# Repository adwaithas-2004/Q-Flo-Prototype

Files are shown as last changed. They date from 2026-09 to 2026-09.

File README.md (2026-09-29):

# Q-Flo: fuel quality and quantity monitor (prototype v1)






An ESP32-based prototype that checks **fuel quality** by capacitive (dielectric) sensing and
measures **fuel quantity** with a flow sensor, then shows both live on a phone or laptop over
Wi-Fi. Built as a B.Tech Electronics and Communication Engineering mini project.

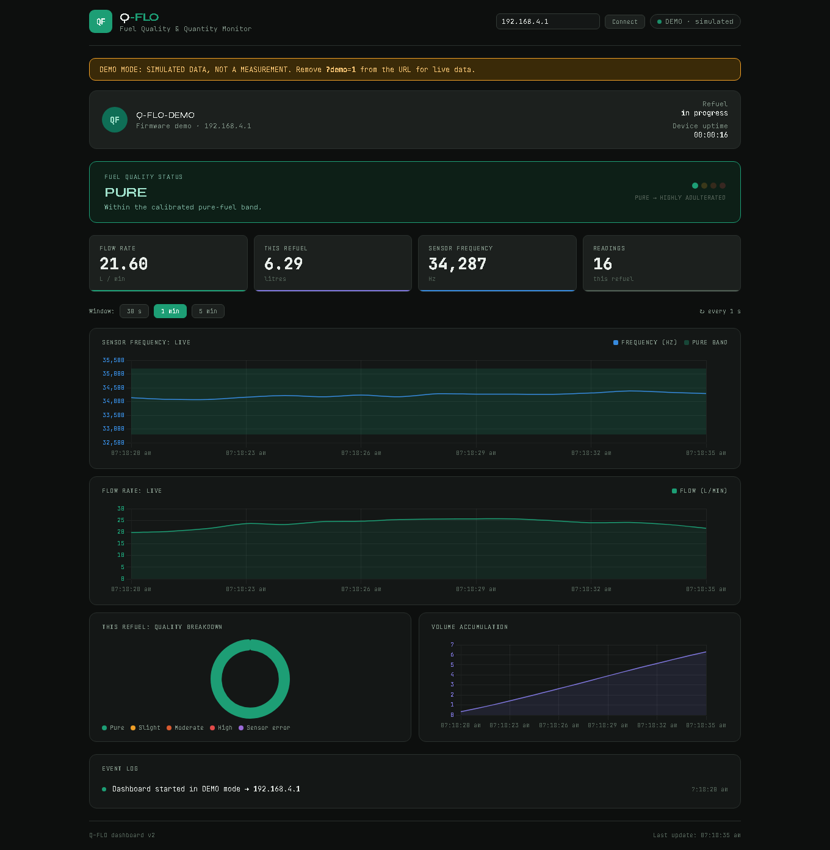
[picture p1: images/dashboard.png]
Q-Flo web dashboard (demo mode)


## Why

Adulterated fuel and short delivery at filling stations are hard for a driver to spot. Q-Flo
explores a low-cost way to watch both while fuel flows: petrol and its common adulterants have
different dielectric constants, so the capacitance of a small sensing cell changes with what's
flowing through it, while a flow meter counts the litres.

## How it works

```mermaid
flowchart LR
    cell["Capacitive cell<br/>fuel is the dielectric"] --> timer["TLC555 astable<br/>20–70 kHz"]
    timer -->|"GPIO32 · hardware pulse counter"| esp["ESP32"]
    flow["YF-S201 flow sensor<br/>hall-effect pulses"] -->|"GPIO27 · hardware pulse counter"| esp
    esp -->|"Wi-Fi access point<br/>web dashboard + JSON API"| user["Phone / laptop"]
    esp -.->|"optional BLE"| user
```

- **Quality.** The cell is the timing capacitor of a 555 oscillator: `f = 1.44 / ((R_A + 2·R_B)·C)`.
  A change in the fuel's dielectric constant shifts the frequency. The firmware compares it
  with a band recorded from pure fuel and classifies each reading as **pure**, **slightly**,
  **moderately** or **highly adulterated**, or flags a sensor fault.
- **Quantity.** The YF-S201 gives about 450 pulses per litre (7.5 Hz per L/min). The firmware
  turns pulses into flow rate and litres per refuelling session.
- **Output.** The ESP32 runs its own Wi-Fi access point and serves a live dashboard and a JSON
  API. Readings can also go out over BLE (set `QFLO_ENABLE_BLE` to 1 in `config.h`).

## Features

- Both signals counted by the ESP32's **PCNT hardware counters**, so the main loop never blocks
  and keeps up with a 70 kHz oscillator while Wi-Fi runs.
- 200 ms frequency gate with a **median filter**; flow rate from the real window length.
- **Refuelling sessions** that start and stop on flow; quality is only judged while fuel flows,
  so an empty chamber can't raise a false alarm.
- **One-touch calibration**: 10 s of readings from pure fuel set the band (mean ± 3σ, at least ±3 %).
- Settings kept in **flash (NVS)**; a **serial console** for status, calibration and CSV logging.
- A **self-contained web dashboard** served by the device (works without internet), plus a
  richer [external dashboard](dashboard/index.html) with charts and an event log.

## Hardware

| Part | Role |
|---|---|
| ESP32 DevKit (ESP32-WROOM-32) | Pulse counting, classification, Wi-Fi/BLE, web server |
| TLC555 (CMOS 555) at 3.3 V | Astable oscillator; the sensing cell is its timing capacitor |
| Capacitive sensing cell | Two plates in the fuel path |
| YF-S201 hall-effect flow sensor | Flow rate and volume |
| BAT85 + 10 kΩ | Level-shifts the 5 V flow signal to 3.3 V |

Schematic (rev B)

KiCad files are in [`hardware/kicad`](hardware/kicad). Wiring, the pin map and component
notes are in [`docs/HARDWARE.md`](docs/HARDWARE.md).

## Getting started

1. **Arduino IDE 2** → Boards Manager → install **esp32 by Espressif Systems** (3.x).
2. Open [`firmware/qflo/qflo.ino`](firmware/qflo/qflo.ino).
3. *(Optional)* copy `secrets.example.h` to `secrets.h` to set your own access-point password
   or join an existing network. `secrets.h` is git-ignored.
4. Board **ESP32 Dev Module** → Upload. Serial monitor at 115200 baud; type `help`.
5. Join the Wi-Fi network **`Q-FLO-XXXX`** (default password `qflo1234`, change it in
   `secrets.h`) and open **http://192.168.4.1**.
6. With pure fuel flowing, run a calibration from the dashboard (or type `cal` in the serial monitor).

The external dashboard: open [`dashboard/index.html`](dashboard/index.html) in a browser.
It connects to `192.168.4.1` by default; add `?device=<ip>` for another address, or `?demo=1`
to see it with simulated data.

## Repository layout

```
firmware/qflo/     ESP32 firmware (Arduino): main loop, sessions, calibration, web API
dashboard/         External web dashboard (single HTML file)
hardware/kicad/    KiCad schematic and libraries
docs/              Hardware notes, calibration procedure, device API
original/          The original mini-project sketches, as demonstrated
images/            Dashboard screenshot and schematic
```

## Limitations and lessons learned

This is a bench prototype, not a product.

- The plates add only 1–2 pF against ~20 pF of stray capacitance, so wiring and temperature
  move the reading. A larger, shielded stainless-steel cell and a capacitance-to-digital
  converter would make the fuel term dominate.
- There's no temperature compensation, and one calibrated band stands in for a proper
  multi-sample calibration.
- The YF-S201 is a water flow sensor: fine for bench demos, not rated for petrol.
- Copper electrodes react with fuel; stainless steel is the right material.

## Safety

Petrol vapour is explosive at very low concentrations. Test outdoors with small volumes, no
ignition sources and an extinguisher at hand. Never power the prototype inside a vehicle's
fuel system.

## Team

Built as a B.Tech Electronics and Communication Engineering mini project (2026) at
Mar Baselios College of Engineering and Technology (MBCET), Thiruvananthapuram, under
APJ Abdul Kalam Technological University.

- Abhishek D
- Adwaith A S ([@adwaithas-2004](https://github.com/adwaithas-2004))
- Aleena Shaji
- Dhanush S

**Project guide:** Mr. H. Aravind Sarma, Assistant Professor, Department of ECE, MBCET.

## License

© 2026 the Q-Flo team. All rights reserved; shared for viewing and evaluation. See [LICENSE](LICENSE).

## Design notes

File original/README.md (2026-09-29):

# Original mini-project sketches

These are the sketches as they were written and demonstrated for the B.Tech mini project,
kept unchanged apart from removing Wi-Fi credentials. The maintained firmware is
[`firmware/qflo`](../firmware/qflo); use that one for new builds.

| Sketch | Purpose |
|---|---|
| `Flow_sensor/` | YF-S201 flow sensor bench test (interrupt counting) |
| `Reference_freq/` | Prints the 555 frequency to record the pure-petrol reference |
| `Comparison/` | Early classifier against a single reference frequency (23,950 Hz) |
| `Final/` | Wi-Fi web-server stub that returns test data at `/data` |
| `wifi_final/` | Fuel quality + flow over Wi-Fi (`/data` JSON), the version in the project report |
| `ble_final/` | Fuel quality + flow over BLE notifications |
| `dashboard/qflo_dashboard_dark.html` | The first web dashboard (replaced by [`dashboard/index.html`](../dashboard/index.html)) |

Wi-Fi credentials were replaced with `YOUR_WIFI_SSID` / `YOUR_WIFI_PASSWORD` placeholders.

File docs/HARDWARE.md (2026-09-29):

# Hardware

## Block diagram

```
                    ┌────────────── fuel path ──────────────┐
 nozzle ──► inlet ──► YF-S201 flow sensor ──► capacitive cell ──► tank
                         │ pulses (7.5 Hz per L/min)   │ C = f(ε_fuel)
                         │                              ▼
                         │                     NE555 / TLC555 astable
                         │                              │ 20–70 kHz square wave
                         ▼                              ▼
                  GPIO27 (PCNT unit)            GPIO32 (PCNT unit)
                         └──────────► ESP32 ◄───────────┘
                                        │ Wi-Fi AP + dashboard, JSON API, (BLE)
                                        ▼
                                  phone / laptop
```

## Pin map (`firmware/qflo/config.h`)

| Signal | ESP32 pin | Notes |
|---|---|---|
| 555 output | GPIO32 | Internal pull-down enabled, so an open wire reads 0 Hz ("NO SIGNAL"). **Max 3.3 V.** |
| YF-S201 signal | GPIO27 | Internal pull-up enabled (open-collector output). **Max 3.3 V.** |
| Sensor/timer supply | 3V3 or 5V | See level-shifting below |
| GND | GND | Star-ground the 555, the cell shield and the ESP32 |

Both inputs use the ESP32's PCNT hardware counter. Any PCNT-capable GPIO works;
avoid GPIO34–39 (no internal pull resistors) and the strapping pins (0, 2, 5, 12, 15).

## Level shifting: don't skip this

The ESP32's GPIO absolute maximum is 3.6 V.

- **Timer.** Preferably use a **TLC555 or LMC555 (CMOS 555) powered from 3.3 V**. It's pin-compatible,
  runs from about 2 V, and has pA-level input currents. That matters with the MΩ timing resistors
  a pF-scale sensor needs. The bipolar NE555 is only specified from 4.5 V. If you keep an NE555 at 5 V,
  put a **10 kΩ / 20 kΩ divider** between pin 3 and GPIO32.
- **YF-S201.** It needs 5 V. If your module has a pull-up to 5 V on the signal wire (measure the idle
  voltage), add the same 10 kΩ / 20 kΩ divider. If it idles near 0 V or floats, the ESP32's internal
  pull-up to 3.3 V is enough.

## 555 timer (astable)

`f = 1.44 / ((R_A + 2·R_B) · C)` with C = sensor capacitance + stray capacitance.

Correct connections, as implemented in the **rev B schematic** ([image](../images/schematic.svg),
KiCad files in [`hardware/kicad`](../hardware/kicad)). The starred lines were wrong on the first
(rev A) board. The PCB layout isn't included because it still carries the rev A nets.

```
+3.3V ── pin 8 VCC, pin 4 RESET; C4 100 nF to GND at pin 8
U1  = TLC555CP (CMOS 555, DIP-8) at +3.3 V
R2  = R_A 10 kΩ : VCC   → pin 7 DISCH
R3  = R_B 1 MΩ  : pin 7 → pins 6 + 2            * (schematic: +5V → pin 6)
pins 2 TRIG + 6 THRES tied together             * (schematic: not connected)
J1  sensor plates: pins 2/6 → GND               (the timing capacitor)
C2  2.2 nF: remove                              * (swamps the ~1–2 pF sensor)
C3  10 nF: pin 5 CONT → GND
pin 3 OUT → GPIO32 directly (TLC555 at 3.3 V; an NE555 at 5 V would need a divider)
flow: J2 pin 3 → D1 (BAT85, cathode to sensor) → GPIO27, R4 10 kΩ pull-up to 3.3 V
```

- With R_A = 10 kΩ and R_B = 1 MΩ the duty cycle is about 50 %, and 34 kHz means about 21 pF total
  timing capacitance, most of it stray. The next cell should raise the sensor's share (see below).
- The firmware's PCNT glitch filter is 200 ns (`FREQ_GLITCH_NS`). If you change R_A/R_B so the LOW
  pulse gets very short, check the duty cycle on a scope.
- Use 1 % metal-film resistors with low temperature coefficient. Put 100 nF decoupling at pin 8
  and 10 nF at pin 5.
- Keep the sensor leads short, rigid and shielded, with the shield grounded. With only a few pF
  of sensor capacitance, moving a wire changes the reading.

## Capacitive cell

| | Prototype v1 | Lessons learned: what the next version should do |
|---|---|---|
| Electrodes | 2 copper plates, 25–35 mm, 5–7 mm gap | **SS316** concentric cylinders or interdigitated plates |
| Insulation | not specified | PTFE / PEEK spacers, fuel-resistant sealing |
| Capacitance | ~1–2 pF (smaller than stray capacitance) | ≥ 20–50 pF, so the fuel term dominates the parasitics |
| Filling | depends on flow | Flooded cell with no trapped air: vertical flow upward, fixed volume |
| Readout | 555 + pulse timing | 555 + PCNT, or better a capacitance-to-digital converter (e.g. AD7746 / FDC1004) with a guard driver |
| Temperature | none | DS18B20 or NTC inside the cell (for compensation) |
| Self-check | none | Switchable reference capacitor, so the ratio cancels 555 and resistor drift |

Copper catalyses petrol oxidation and gum formation. Avoid copper, brass and zinc in the wetted path.

## Flow sensor

The YF-S201 is a **water** flow sensor. It is rated 1–30 L/min (car nozzles often run
30–40 L/min), has hobby-grade accuracy, and its plastics are not rated for petrol. It's fine
for a bench demo with small volumes. It is not suitable for real fuel; that needs a
fuel-rated meter.

## Power

- Bench: 5 V USB is fine.
- Vehicle: 12 V battery → **automotive buck converter** (with reverse-polarity protection,
  a load-dump TVS and a fuse) → 5 V / 3.3 V. A linear AMS1117 or LM7805 dropping 12 V wastes 2 W as heat.
- The engine and usually the ignition are **off during refuelling**. The device therefore needs a
  permanent (unswitched) supply plus a low-power sleep mode, woken by a fuel-lid switch.

## Current prototype bill of materials

| Qty | Part |
|-----|---|
| 1 | ESP32 DevKit (ESP32-WROOM-32) |
| 1 | NE555 (→ replace with TLC555) + R1, R2, 10 nF, 100 nF |
| 2 | Copper plates 25–35 mm (→ SS316) |
| 1 | YF-S201 hall-effect flow sensor |
| 1 | Voltage regulator (AMS1117 / LM7805) (→ buck converter) |
| – | PCB, connectors, tubing, flow chamber |

## Safety

Petrol vapour is explosive at very low concentrations. Test outdoors or in a fume hood with
small volumes and no ignition sources, and keep an extinguisher at hand. Never power the
prototype inside a vehicle's fuel system.

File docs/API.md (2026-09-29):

# Q-FLO device API

The device always runs its own access point, **`Q-FLO-XXXX`** (password in `secrets.h`,
default `qflo1234`). The dashboard is at **http://192.168.4.1**. If it also joined a network
(`secrets.h`), it is reachable at its LAN IP and at **http://qflo.local**.

All JSON responses send `Access-Control-Allow-Origin: *`, so an external web dashboard
can call the device directly.

## Endpoints

| Method | Path | Purpose |
|---|---|---|
| GET | `/` | Built-in dashboard (single self-contained page) |
| GET | `/api/data` | Live readings, session, calibration, thresholds |
| GET | `/data` | Same as `/api/data`. The v1 path, kept so older dashboards still work |
| POST | `/api/settings` | Form fields (all optional): `pureMin`, `pureMax`, `slight`, `moderate` (Hz), `ppl` (pulses/L), `bench` (`0`/`1`), `defaults=1` |
| POST | `/api/calibrate` | Start a 10 s pure-fuel reference capture → `202` |
| POST | `/api/session/reset` | Clear the current refuelling session |

Example:

```bash
curl -X POST http://192.168.4.1/api/settings -d "pureMin=33000&pureMax=35400&bench=1"
```

## `/api/data` response

```json
{
  "freq": 34105.0,            // Hz, median-filtered            (v1 field)
  "quality": "PURE PETROL",   // label shown to the user         (v1 field)
  "flow": 12.40,              // L/min                           (v1 field)
  "total": 5.672,             // litres in the current/last refuel (v1: since boot)
  "class": "pure",            // machine key, see below
  "signal": true,             // false = no 555 signal
  "rawFreq": 34118.2,         // Hz, last 200 ms gate
  "state": "fueling",         // idle | fueling | done
  "bench": false,
  "session": {
    "litres": 5.672, "durationS": 42, "avgFreq": 34101.2, "sdFreq": 85.3, "samples": 210,
    "verdict": "PURE PETROL", "verdictClass": "pure",
    "counts": { "pure": 200, "slight": 10, "moderate": 0, "high": 0, "fault": 0, "no_signal": 0 }
  },
  "lifetime": 123.45,
  "cal": { "state": "ok", "progress": 0, "mean": 34150.0, "sd": 60.2, "samples": 50 },
  "th": { "pureMin": 33125.5, "pureMax": 35174.5, "slight": 5000, "moderate": 15000, "ppl": 450 },
  "uptimeS": 3600, "fw": "2.0.0", "ap": "Q-FLO-3A7C", "staIp": "192.168.1.42"
}
```

### Quality classes

| `class` | `quality` label | Meaning | Dashboard colour |
|---|---|---|---|
| `pure` | PURE PETROL | `pureMin ≤ f ≤ pureMax` | green |
| `slight` | SLIGHTLY ADULTERATED | `0 < f − pureMax ≤ slight` | yellow |
| `moderate` | MODERATELY ADULTERATED | `slight < f − pureMax ≤ moderate` | orange |
| `high` | HIGHLY ADULTERATED | `f − pureMax > moderate` | red |
| `fault` | SENSOR ERROR | `f < pureMin` | purple |
| `no_signal` | NO SIGNAL | `f < 1 kHz` (timer dead or disconnected) | grey |
| `waiting` | WAITING FOR FUEL | no flow, so quality is not judged | grey |

`quality` shows the **live** class while fuel flows, the **session verdict** (from the session's
mean frequency) after the refuel ends, and `WAITING FOR FUEL` before the first refuel.

## BLE (optional, `QFLO_ENABLE_BLE 1`)

- Device name: same as the access point (`Q-FLO-XXXX`)
- Service `5f1b0001-8c3e-4d6a-9a57-3b2f6e0c9a10`
- Characteristic `5f1b0002-8c3e-4d6a-9a57-3b2f6e0c9a10`: read + notify, once per second:
  `{"f":34105,"q":"pure","fl":12.40,"t":5.672,"s":"fueling"}`
- The payload is about 70 bytes, so the client must request an MTU above 23 (for example 185).
  nRF Connect and most Android/iOS libraries let you do this.
- Wi-Fi + BLE needs *Tools → Partition Scheme → Huge APP*.

## Serial console (115200 baud)

`help` · `status` · `cal` · `reset` · `bench on|off` · `csv on|off` · `ppl <n>` · `defaults`

## Security note

The API has no authentication. The access-point password is the only protection, so change it
in `secrets.h`. Before joining shared networks, add an API token and move to HTTPS/MQTT over
TLS.

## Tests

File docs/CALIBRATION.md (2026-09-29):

# Calibration and validation

Everything here works with the firmware through either the **dashboard**
(*Calibration & settings*) or the **serial console** at 115200 baud (type `help`).

> Work outdoors or in a fume hood with small volumes, no ignition sources and an
> extinguisher at hand. Keep fuel samples in labelled, closed containers.

## 1. Flow sensor (pulses per litre)

The YF-S201 datasheet figure (7.5 Hz per L/min = 450 pulses/L) is for **water**.
Petrol is less viscous, so calibrate with the fuel you'll measure.

1. Run `reset` so the session counter starts at zero.
2. Pour a known volume (at least 2 L, measured in a graduated cylinder or a 5 L
   legal-metrology measure) through the sensor at a steady, realistic rate.
3. Read **This refuel** (litres) on the dashboard.
4. New factor = `current_ppl × displayed_litres / actual_litres`. Set it with `ppl <value>`
   or in the settings form.
5. Repeat at three flow rates (slow, medium, fast), then use the average. If the factor varies
   by more than a few percent across rates, the sensor is outside its linear range at those rates.

## 2. Dielectric reference (pure band)

1. Clean and dry the cell, then flush it twice with the reference fuel.
2. Fill it completely, with no bubbles. Wait about 60 s for the reading to settle.
3. Turn on **bench mode** (`bench on`) so the device classifies without flow.
4. Start calibration (`cal`, or the dashboard button). It averages 10 s of readings and sets the pure band to
   `mean ± max(3·sd, 3 % of mean)`. Settings are stored in flash, so no re-flash is needed.
5. Do this three times with fresh fills. If the three means differ by more than the band
   width, the cell isn't repeatable yet.

Record the reference fuel for every calibration: pump or brand, date, **E-grade (E20?)**, and temperature.

## 3. Collecting a validation dataset

Turn on CSV streaming with `csv on`. The device prints five lines per second:

```
ms,raw_hz,filtered_hz,flow_lpm,session_l,class,state
123400,34118.2,34105.0,0.000,0.0000,pure,idle
```

Capture it with the Arduino IDE serial monitor (copy and paste), PuTTY logging, or a small
Python script. Save one file per run, named like `2026-10-02_run07_P+K10.csv`.

### Suggested protocol

| Factor | Levels |
|---|---|
| Base fuel | market E20 petrol from ≥ 3 pumps; diesel |
| Adulterant | kerosene, diesel (in petrol); kerosene (in diesel); water (small %) |
| Fraction (by volume) | 0, 2, 5, 10, 20, 30, 50 % |
| Replicates | ≥ 5 independent fills per level, in randomised order |
| Temperature | log it, and test at least a cool and a warm condition |

Keep a sample sheet (`data/samples.csv`) alongside the logs:

```
run_id,date,operator,base_fuel,source,adulterant,fraction_pct,temp_c,file,notes
run07,2026-10-02,AD,E20 petrol,Pump A,kerosene,10,29.5,2026-10-02_run07_P+K10.csv,
```

From this you can compute:
- A calibration curve (frequency against fraction), with its linearity and slope (sensitivity).
- A **limit of detection**: the smallest fraction distinguishable from 0 % at, say, 95 % confidence.
- Repeatability (same day) and reproducibility (different days, fills and temperatures).
- A **confusion matrix** from a blind test, where one teammate prepares the samples and another measures them.

These numbers are what a paper reviewer, a customer pilot or a grant panel will ask for.
They also form the dataset any future ML model needs.

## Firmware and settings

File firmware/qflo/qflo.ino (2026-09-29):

/*
   Q-FLO v2 - fuel quality + quantity monitor at the refuelling point

   Quality : capacitive cell (fuel = dielectric) timing an NE555 astable;
             the ESP32 counts the 555 frequency in hardware (PCNT).
   Quantity: YF-S201 turbine flow sensor, also counted in hardware.

   Board : ESP32 Dev Module, Arduino-ESP32 core 3.x
   Output: web dashboard at http://192.168.4.1 (device access point),
           JSON at /api/data (and /data for v1 dashboards), serial console.

   Wiring, calibration and API: see README.md and docs/.
*/

#include <ESPmDNS.h>
#include <WebServer.h>
#include <WiFi.h>

#include "FuelLogic.h"
#include "PulseCounter.h"
#include "Settings.h"
#include "config.h"
#include "dashboard.h"

#if __has_include("secrets.h")
#include "secrets.h"
#endif
#ifndef QFLO_AP_PASSWORD
#define QFLO_AP_PASSWORD "qflo1234"  // default; override in secrets.h
#endif

#if QFLO_ENABLE_BLE
#include <BLE2902.h>
#include <BLEDevice.h>
#include <BLEServer.h>
#endif

#define QFLO_STR_(x) #x
#define QFLO_STR(x) QFLO_STR_(x)

#if ESP_ARDUINO_VERSION_MAJOR < 3
#error "Q-FLO needs the esp32 Arduino core 3.x (Boards Manager > esp32 by Espressif Systems)"
#endif

// ---------------- HARDWARE ----------------
PulseCounter freqCounter;
PulseCounter flowCounter;
Settings settings;
WebServer server(80);
char apSsid[24];

// ---------------- LIVE READINGS ----------------
float rawHz = 0;       // last gate
float filteredHz = 0;  // median of the last FREQ_MEDIAN_WINDOW gates
float freqWindow[FREQ_MEDIAN_WINDOW];
uint8_t freqIndex = 0;
uint8_t freqFill = 0;
bool signalOk = false;
float flowLpm = 0;
FuelClass liveClass = FuelClass::NoSignal;

uint32_t lastGateUs = 0;
uint32_t lastGateMs = 0;
uint32_t lastFlowWindowMs = 0;
uint32_t lastReportMs = 0;

// ---------------- REFUELLING SESSION ----------------
// Idle -> Fueling when flow starts; Fueling -> Done after SESSION_END_IDLE_MS
// without flow. Quality is only judged while fuel is flowing, because an
// empty chamber (air) would otherwise read as "highly adulterated".
enum class SessionState : uint8_t { Idle, Fueling, Done };
SessionState sessionState = SessionState::Idle;
uint32_t sessionPulses = 0;
uint32_t sessionStartMs = 0;
uint32_t sessionEndMs = 0;
uint32_t lastFlowSeenMs = 0;
RunningStats sessionFreq;
uint32_t sessionCounts[kFuelClassCount] = {};

// ---------------- CALIBRATION ----------------
enum class CalResult : uint8_t { None, Ok, Failed };
bool calActive = false;
uint32_t calStartMs = 0;
RunningStats calStats;
CalResult calResult = CalResult::None;
float calMean = 0;
float calSd = 0;
uint32_t calSamples = 0;

// ---------------- SERIAL ----------------
bool csvMode = false;
char serialLine[48];
uint8_t serialLen = 0;

// ---------------- HELPERS ----------------
const char* sessionStateKey() {
  switch (sessionState) {
    case SessionState::Fueling: return "fueling";
    case SessionState::Done:    return "done";
    default:                    return "idle";
  }
}

const char* calResultKey() {
  if (calActive) return "running";
  switch (calResult) {
    case CalResult::Ok:     return "ok";
    case CalResult::Failed: return "failed";
    default:                return "none";
  }
}

float sessionLitres() {
  return sessionPulses / settings.pulsesPerLitre;
}

uint32_t sessionDurationMs() {
  if (sessionState == SessionState::Idle) return 0;
  uint32_t end = sessionState == SessionState::Fueling ? millis() : sessionEndMs;
  return end - sessionStartMs;
}

bool fuelPresent() {
  return settings.benchMode ||
         (sessionState == SessionState::Fueling && flowLpm >= FLOW_START_LPM);
}

FuelClass sessionVerdict() {
  if (sessionFreq.n == 0) {
    return sessionCounts[(uint8_t)FuelClass::NoSignal] ? FuelClass::NoSignal : FuelClass::Waiting;
  }
  return classifyFrequency(sessionFreq.mean, settings.th, FREQ_MIN_VALID_HZ);
}

// What the user should see right now: the live reading while fuel flows,
// the result of the last refuel afterwards.
FuelClass displayedClass() {
  if (settings.benchMode || sessionState == SessionState::Fueling) return liveClass;
  if (sessionState == SessionState::Done) return sessionVerdict();
  return liveClass;  // Idle: Waiting or NoSignal
}

// ---------------- SESSION ----------------
void startSession(uint32_t nowMs) {
  sessionState = SessionState::Fueling;
  sessionPulses = 0;
  sessionStartMs = nowMs;
  sessionFreq.reset();
  memset(sessionCounts, 0, sizeof(sessionCounts));
  Serial.println(F(">> Refuelling started"));
}

void endSession() {
  sessionState = SessionState::Done;
  sessionEndMs = lastFlowSeenMs;
  settings.saveLifetime();
  Serial.printf(">> Refuelling finished: %.3f L in %lu s, avg %.0f Hz -> %s\n",
                sessionLitres(), (unsigned long)(sessionDurationMs() / 1000),
                sessionFreq.mean, fuelClassLabel(sessionVerdict()));
}

void resetSession() {
  sessionState = SessionState::Idle;
  sessionPulses = 0;
  sessionFreq.reset();
  memset(sessionCounts, 0, sizeof(sessionCounts));
}

// ---------------- CALIBRATION ----------------
// Fill the cell with known-pure fuel, then start: the pure band becomes
// mean +/- max(k*sd, pct*mean) of the readings over CAL_DURATION_MS.
void startCalibration() {
  calActive = true;
  calStartMs = millis();
  calStats.reset();
  Serial.println(F(">> Calibration started: keep known-pure fuel in the sensor"));
}

void updateCalibration() {
  if (!calActive || millis() - calStartMs < CAL_DURATION_MS) return;
  calActive = false;
  calSamples = calStats.n;
  if (calStats.n < CAL_MIN_SAMPLES) {
    calResult = CalResult::Failed;
    Serial.println(F(">> Calibration failed: no stable 555 signal"));
    return;
  }
  calMean = calStats.mean;
  calSd = calStats.sd();
  float halfBand = max(CAL_SIGMA_K * calSd, CAL_MIN_HALF_BAND_PCT * calMean);
  settings.th.pureMinHz = calMean - halfBand;
  settings.th.pureMaxHz = calMean + halfBand;
  settings.save();
  calResult = CalResult::Ok;
  Serial.printf(">> Calibration OK: mean %.1f Hz, sd %.1f Hz (n=%lu) -> pure band %.0f..%.0f Hz\n",
                calMean, calSd, (unsigned long)calSamples,
                settings.th.pureMinHz, settings.th.pureMaxHz);
}

// ---------------- MEASUREMENT ----------------
void updateFrequency() {
  uint32_t nowUs = micros();
  uint32_t edges = freqCounter.take();
  uint32_t elapsedUs = nowUs - lastGateUs;
  lastGateUs = nowUs;
  if (elapsedUs == 0) return;

  rawHz = edges * 1e6f / elapsedUs;
  freqWindow[freqIndex] = rawHz;
  freqIndex = (freqIndex + 1) % FREQ_MEDIAN_WINDOW;
  if (freqFill < FREQ_MEDIAN_WINDOW) freqFill++;
  filteredHz = medianOf(freqWindow, freqFill);
  signalOk = filteredHz >= FREQ_MIN_VALID_HZ;

  FuelClass c = classifyFrequency(filteredHz, settings.th, FREQ_MIN_VALID_HZ);
  liveClass = (c == FuelClass::NoSignal || fuelPresent()) ? c : FuelClass::Waiting;

  if (calActive && rawHz >= FREQ_MIN_VALID_HZ) calStats.add(rawHz);

  if (sessionState == SessionState::Fueling && fuelPresent()) {
    sessionCounts[(uint8_t)c]++;
    if (signalOk) sessionFreq.add(filteredHz);
  }

  if (csvMode) {
    Serial.printf("%lu,%.1f,%.1f,%.3f,%.4f,%s,%s\n", (unsigned long)millis(), rawHz, filteredHz,
                  flowLpm, sessionLitres(), fuelClassKey(liveClass), sessionStateKey());
  }
}

void updateFlow() {
  uint32_t nowMs = millis();
  uint32_t pulses = flowCounter.take();
  uint32_t elapsedMs = nowMs - lastFlowWindowMs;
  lastFlowWindowMs = nowMs;

  // Use the real window length: the v1 code assumed exactly 1 s, but its
  // loop took ~1.2 s (and up to 40 s with no 555 signal).
  float litres = pulses / settings.pulsesPerLitre;
  flowLpm = elapsedMs ? litres * 60000.0f / elapsedMs : 0;
  settings.lifetimeLitres += litres;

  if (flowLpm >= FLOW_START_LPM) {
    if (sessionState != SessionState::Fueling) startSession(nowMs);
    lastFlowSeenMs = nowMs;
  }
  if (sessionState == SessionState::Fueling) {
    sessionPulses += pulses;
    if (nowMs - lastFlowSeenMs >= SESSION_END_IDLE_MS) endSession();
  }
}

// ---------------- JSON ----------------
size_t buildDataJson(char* out, size_t cap) {
  FuelClass shown = displayedClass();
  FuelClass verdict = sessionVerdict();
  uint32_t calProgress = calActive ? min<uint32_t>(100, (millis() - calStartMs) * 100 / CAL_DURATION_MS) : 0;
  const uint32_t* k = sessionCounts;

  int n = snprintf(out, cap,
    "{\"freq\":%.1f,\"quality\":\"%s\",\"flow\":%.2f,\"total\":%.3f,"
    "\"class\":\"%s\",\"signal\":%s,\"rawFreq\":%.1f,\"state\":\"%s\",\"bench\":%s,"
    "\"session\":{\"litres\":%.3f,\"durationS\":%lu,\"avgFreq\":%.1f,\"sdFreq\":%.1f,\"samples\":%lu,"
    "\"verdict\":\"%s\",\"verdictClass\":\"%s\","
    "\"counts\":{\"pure\":%lu,\"slight\":%lu,\"moderate\":%lu,\"high\":%lu,\"fault\":%lu,\"no_signal\":%lu}},"
    "\"lifetime\":%.2f,"
    "\"cal\":{\"state\":\"%s\",\"progress\":%lu,\"mean\":%.1f,\"sd\":%.1f,\"samples\":%lu},"
    "\"th\":{\"pureMin\":%.1f,\"pureMax\":%.1f,\"slight\":%.1f,\"moderate\":%.1f,\"ppl\":%.2f},"
    "\"uptimeS\":%lu,\"fw\":\"%s\",\"ap\":\"%s\",\"staIp\":\"%s\"}",
    filteredHz, fuelClassLabel(shown), flowLpm, sessionLitres(),
    fuelClassKey(shown), signalOk ? "true" : "false", rawHz, sessionStateKey(),
    settings.benchMode ? "true" : "false",
    sessionLitres(), (unsigned long)(sessionDurationMs() / 1000), sessionFreq.mean,
    sessionFreq.sd(), (unsigned long)sessionFreq.n,
    fuelClassLabel(verdict), fuelClassKey(verdict),
    (unsigned long)k[(uint8_t)FuelClass::Pure], (unsigned long)k[(uint8_t)FuelClass::Slight],
    (unsigned long)k[(uint8_t)FuelClass::Moderate], (unsigned long)k[(uint8_t)FuelClass::High],
    (unsigned long)k[(uint8_t)FuelClass::SensorFault], (unsigned long)k[(uint8_t)FuelClass::NoSignal],
    settings.lifetimeLitres,
    calResultKey(), (unsigned long)calProgress, calMean, calSd, (unsigned long)calSamples,
    settings.th.pureMinHz, settings.th.pureMaxHz, settings.th.slightBandHz,
    settings.th.moderateBandHz, settings.pulsesPerLitre,
    (unsigned long)(millis() / 1000), QFLO_FW_VERSION, apSsid,
    WiFi.status() == WL_CONNECTED ? WiFi.localIP().toString().c_str() : "");
  return n > 0 ? min<size_t>(n, cap - 1) : 0;
}

// ---------------- WEB ----------------
void sendCors() {
  server.sendHeader("Access-Control-Allow-Origin", "*");
  server.sendHeader("Access-Control-Allow-Methods", "GET, POST, OPTIONS");
  server.sendHeader("Access-Control-Allow-Headers", "Content-Type");
}

void sendJson(int code, const char* body) {
  sendCors();
  server.sendHeader("Cache-Control", "no-store");
  server.send(code, "application/json", body);
}

void handleData() {
  static char json[1400];
  buildDataJson(json, sizeof(json));
  sendJson(200, json);
}

// POST /api/settings  (form fields, all optional)
// pureMin, pureMax, slight, moderate [Hz], ppl [pulses/L], bench [0|1], defaults [1]
void handleSettings() {
  if (server.hasArg("defaults")) {
    settings.setDefaults();
    settings.save();
    sendJson(200, "{\"ok\":true}");
    return;
  }
  Thresholds th = settings.th;
  if (server.hasArg("pureMin"))  th.pureMinHz = server.arg("pureMin").toFloat();
  if (server.hasArg("pureMax"))  th.pureMaxHz = server.arg("pureMax").toFloat();
  if (server.hasArg("slight"))   th.slightBandHz = server.arg("slight").toFloat();
  if (server.hasArg("moderate")) th.moderateBandHz = server.arg("moderate").toFloat();
  if (!thresholdsValid(th)) {
    sendJson(400, "{\"ok\":false,\"error\":\"need 0 < pureMin < pureMax and 0 < slight < moderate\"}");
    return;
  }
  float ppl = server.hasArg("ppl") ? server.arg("ppl").toFloat() : settings.pulsesPerLitre;
  if (!(ppl > 1 && ppl < 100000)) {
    sendJson(400, "{\"ok\":false,\"error\":\"ppl out of range\"}");
    return;
  }
  settings.th = th;
  settings.pulsesPerLitre = ppl;
  if (server.hasArg("bench")) settings.benchMode = server.arg("bench") == "1";
  settings.save();
  sendJson(200, "{\"ok\":true}");
}

void handleCalibrate() {
  startCalibration();
  sendJson(202, "{\"ok\":true,\"durationMs\":" QFLO_STR(CAL_DURATION_MS) "}");
}

void handleSessionReset() {
  resetSession();
  sendJson(200, "{\"ok\":true}");
}

void setupWeb() {
  server.on("/", HTTP_GET, [] { server.send_P(200, "text/html; charset=utf-8", DASHBOARD_HTML); });
  server.on("/data", HTTP_GET, handleData);      // v1 path, kept for existing dashboards
  server.on("/api/data", HTTP_GET, handleData);
  server.on("/api/settings", HTTP_POST, handleSettings);
  server.on("/api/calibrate", HTTP_POST, handleCalibrate);
  server.on("/api/session/reset", HTTP_POST, handleSessionReset);
  server.onNotFound([] {
    if (server.method() == HTTP_OPTIONS) {  // CORS preflight for external dashboards
      sendCors();
      server.send(204);
    } else {
      sendJson(404, "{\"error\":\"not found\"}");
    }
  });
  server.begin();
}

// ---------------- WI-FI ----------------
void setupWifi() {
  uint64_t mac = ESP.getEfuseMac();
  snprintf(apSsid, sizeof(apSsid), "%s%02X%02X", AP_SSID_PREFIX,
           (uint8_t)(mac >> 32), (uint8_t)(mac >> 40));

  WiFi.setHostname(HOSTNAME);
#ifdef QFLO_STA_SSID
  WiFi.mode(WIFI_AP_STA);
  WiFi.setAutoReconnect(true);
  WiFi.begin(QFLO_STA_SSID, QFLO_STA_PASSWORD);  // non-blocking; v1 waited forever here
#else
  WiFi.mode(WIFI_AP);
#endif
  WiFi.softAP(apSsid, QFLO_AP_PASSWORD);

  if (MDNS.begin(HOSTNAME)) MDNS.addService("http", "tcp", 80);

  Serial.printf("Access point: %s  ->  http://%s\n", apSsid, WiFi.softAPIP().toString().c_str());
}

void announceStationIp() {
#ifdef QFLO_STA_SSID
  static bool announced = false;
  bool connected = WiFi.status() == WL_CONNECTED;
  if (connected && !announced) {
    Serial.printf("Joined %s  ->  http://%s  (or http://%s.local)\n", QFLO_STA_SSID,
                  WiFi.localIP().toString().c_str(), HOSTNAME);
  }
  announced = connected;
#endif
}

// ---------------- BLE (optional) ----------------
#if QFLO_ENABLE_BLE
BLECharacteristic* bleData = nullptr;

void setupBle() {
  BLEDevice::init(apSsid);
  BLEServer* bleServer = BLEDevice::createServer();
  bleServer->advertiseOnDisconnect(true);  // v1 became invisible after the first disconnect
  BLEService* service = bleServer->createService(BLE_SERVICE_UUID);
  bleData = service->createCharacteristic(
      BLE_DATA_UUID, BLECharacteristic::PROPERTY_READ | BLECharacteristic::PROPERTY_NOTIFY);
  bleData->addDescriptor(new BLE2902());
  service->start();
  BLEAdvertising* advertising = BLEDevice::getAdvertising();
  advertising->addServiceUUID(BLE_SERVICE_UUID);
  advertising->start();
}

// Compact JSON (~70 bytes): clients must request an MTU > 23 to receive it whole.
void bleNotify() {
  char buf[128];
  int n = snprintf(buf, sizeof(buf), "{\"f\":%.0f,\"q\":\"%s\",\"fl\":%.2f,\"t\":%.3f,\"s\":\"%s\"}",
                   filteredHz, fuelClassKey(displayedClass()), flowLpm, sessionLitres(),
                   sessionStateKey());
  if (n <= 0) return;
  bleData->setValue((uint8_t*)buf, min<size_t>(n, sizeof(buf) - 1));
  bleData->notify();
}
#endif

// ---------------- SERIAL ----------------
void printReport() {
  Serial.println(F("------ Q-FLO ------"));
  if (signalOk) {
    Serial.printf("Frequency : %.0f Hz (last gate %.0f Hz)\n", filteredHz, rawHz);
  } else {
    Serial.println(F("Frequency : NO SIGNAL - check 555 / sensor wiring"));
  }
  Serial.printf("Quality   : %s%s\n", fuelClassLabel(displayedClass()),
                settings.benchMode ? "  [bench mode]" : "");
  Serial.printf("Flow rate : %.2f L/min\n", flowLpm);
  Serial.printf("This fill : %.3f L (%s, %lu s)\n", sessionLitres(), sessionStateKey(),
                (unsigned long)(sessionDurationMs() / 1000));
  Serial.printf("Lifetime  : %.2f L\n", settings.lifetimeLitres);
}

void printHelp() {
  Serial.println(F(
    "Commands:\n"
    "  help          this list\n"
    "  status        print a report now\n"
    "  cal           capture the pure-fuel reference (10 s)\n"
    "  reset         clear the current refuelling session\n"
    "  bench on|off  classify without flow (static samples)\n"
    "  csv on|off    stream raw data as CSV, 5 lines/s\n"
    "  ppl <n>       set flow pulses per litre\n"
    "  defaults      restore factory thresholds"));
}

void runCommand(char* line) {
  char* cmd = strtok(line, " ");
  char* arg = strtok(nullptr, " ");
  if (!cmd) return;
  String c(cmd);
  c.toLowerCase();
  bool on = arg && (strcmp(arg, "on") == 0 || strcmp(arg, "1") == 0);

  if (c == "help") printHelp();
  else if (c == "status") printReport();
  else if (c == "cal") startCalibration();
  else if (c == "reset") { resetSession(); Serial.println(F(">> Session cleared")); }
  else if (c == "bench") { settings.benchMode = on; settings.save(); Serial.printf(">> Bench mode %s\n", on ? "ON" : "OFF"); }
  else if (c == "csv") {
    csvMode = on;
    if (on) Serial.println(F("ms,raw_hz,filtered_hz,flow_lpm,session_l,class,state"));
  }
  else if (c == "ppl" && arg) {
    float ppl = atof(arg);
    if (ppl > 1 && ppl < 100000) { settings.pulsesPerLitre = ppl; settings.save(); Serial.printf(">> %.2f pulses/L saved\n", ppl); }
    else Serial.println(F(">> ppl out of range"));
  }
  else if (c == "defaults") { settings.setDefaults(); settings.save(); Serial.println(F(">> Defaults restored")); }
  else Serial.println(F("Unknown command - type 'help'"));
}

void handleSerial() {
  while (Serial.available()) {
    char ch = Serial.read();
    if (ch == '\r') continue;
    if (ch == '\n') {
      serialLine[serialLen] = '\0';
      runCommand(serialLine);
      serialLen = 0;
    } else if (serialLen < sizeof(serialLine) - 1) {
      serialLine[serialLen++] = ch;
    }
  }
}

// ---------------- SETUP ----------------
void setup() {
  Serial.begin(115200);
  delay(200);
  Serial.printf("\nQ-FLO firmware %s\n", QFLO_FW_VERSION);

  settings.load();

  // Pull-down on the 555 input: a disconnected sensor reads 0 Hz instead of noise.
  if (!freqCounter.begin(PIN_FREQ, FREQ_GLITCH_NS, GPIO_PULLDOWN_ONLY)) {
    Serial.println(F("ERROR: frequency counter init failed"));
  }
  // YF-S201 output is open-collector: needs a pull-up.
  if (!flowCounter.begin(PIN_FLOW, FLOW_GLITCH_NS, GPIO_PULLUP_ONLY)) {
    Serial.println(F("ERROR: flow counter init failed"));
  }
  lastGateUs = micros();
  lastGateMs = lastFlowWindowMs = millis();

  setupWifi();
  setupWeb();
#if QFLO_ENABLE_BLE
  setupBle();
#endif
  printHelp();
}

// ---------------- LOOP ----------------
// Nothing in here blocks, so the web server answers immediately
// (v1 blocked ~1.2 s per loop, and ~40 s when the 555 had no signal).
void loop() {
  server.handleClient();
  handleSerial();

  uint32_t now = millis();
  if (now - lastGateMs >= FREQ_GATE_MS) {
    lastGateMs = now;
    updateFrequency();
  }
  if (now - lastFlowWindowMs >= FLOW_WINDOW_MS) {
    updateFlow();
  }
  updateCalibration();

  if (now - lastReportMs >= REPORT_INTERVAL_MS) {
    lastReportMs = now;
    if (!csvMode) printReport();
    announceStationIp();
#if QFLO_ENABLE_BLE
    bleNotify();
#endif
  }
  delay(2);
}

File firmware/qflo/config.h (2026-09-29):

#pragma once

// Q-FLO build-time configuration.
// Values marked "default" are only used until you change them from the
// dashboard / serial console; after that the saved values (NVS) win.

#define QFLO_FW_VERSION "2.0.0"

// ---------------- PINS (ESP32 DevKit) ----------------
// Both inputs are 3.3 V only. If the NE555 or the YF-S201 runs from 5 V,
// put a divider / level shifter in front of the pin (see docs/HARDWARE.md).
#define PIN_FREQ 32   // NE555 output (capacitive fuel sensor)
#define PIN_FLOW 27   // YF-S201 flow sensor signal

// ---------------- FREQUENCY MEASUREMENT ----------------
// The 555 output is counted in hardware (PCNT) over a fixed gate.
// 200 ms gate -> 1 count = 5 Hz resolution (pulseIn() gave ~1.2 kHz per sample).
#define FREQ_GATE_MS        200
#define FREQ_MEDIAN_WINDOW  5        // median of the last 5 gates (~1 s)
#define FREQ_MIN_VALID_HZ   1000.0f  // below this the oscillator is treated as dead
#define FREQ_GLITCH_NS      200      // keep short: a 555 with R1 >> R2 has very short LOW pulses

// ---------------- FLOW MEASUREMENT ----------------
// YF-S201 datasheet: f(Hz) = 7.5 x Q(L/min)  ->  7.5 x 60 = 450 pulses per litre.
// That figure is for water; calibrate with petrol (docs/CALIBRATION.md).
#define FLOW_PULSES_PER_LITRE_DEFAULT 450.0f
#define FLOW_WINDOW_MS       1000
#define FLOW_GLITCH_NS       10000
#define FLOW_START_LPM       0.5f    // flow above this starts / sustains a refuelling session
#define SESSION_END_IDLE_MS  10000   // a session ends after this long without flow

// ---------------- CLASSIFICATION DEFAULTS ----------------
// Reproduces Table 2 of the Q-FLO paper. Re-run the calibration ("cal") with
// known-pure fuel on your own sensor cell before trusting these numbers.
#define PURE_MIN_HZ_DEFAULT      23950.0f
#define PURE_MAX_HZ_DEFAULT      34196.0f
#define SLIGHT_BAND_HZ_DEFAULT    5000.0f   // pureMax < f <= pureMax + 5 kHz   (~ up to 10 %)
#define MODERATE_BAND_HZ_DEFAULT 15000.0f   // pureMax + 5 kHz < f <= + 15 kHz  (~ 10-30 %)

// ---------------- CALIBRATION ----------------
// Pure band = mean +/- max(CAL_SIGMA_K * sd, CAL_MIN_HALF_BAND_PCT * mean)
#define CAL_DURATION_MS        10000
#define CAL_MIN_SAMPLES        20
#define CAL_SIGMA_K            3.0f
#define CAL_MIN_HALF_BAND_PCT  0.03f

// ---------------- NETWORK ----------------
// The device always starts its own access point (Q-FLO-XXXX, dashboard at
// http://192.168.4.1). Put credentials in secrets.h to also join a network.
#define AP_SSID_PREFIX "Q-FLO-"
#define HOSTNAME       "qflo"        // http://qflo.local on a shared network

// ---------------- REPORTING ----------------
#define REPORT_INTERVAL_MS 1000

// ---------------- OPTIONAL BLE ----------------
// Wi-Fi + Bluetooth together do not fit the default partition table:
// set Tools > Partition Scheme > "Huge APP (3MB No OTA/1MB SPIFFS)" when enabling.
#ifndef QFLO_ENABLE_BLE
#define QFLO_ENABLE_BLE 0
#endif
#define BLE_SERVICE_UUID "5f1b0001-8c3e-4d6a-9a57-3b2f6e0c9a10"
#define BLE_DATA_UUID    "5f1b0002-8c3e-4d6a-9a57-3b2f6e0c9a10"

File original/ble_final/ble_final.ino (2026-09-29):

#include <BLEDevice.h>
#include <BLEServer.h>
#include <BLEUtils.h>
#include <BLE2902.h>

// ---------------- PINS ----------------
#define FREQ_PIN 32
#define FLOW_PIN 27

// ---------------- PETROL RANGE ----------------
float F_petrol_min = 23950.0;
float F_petrol_max = 34196.0;

// ---------------- FLOW VARIABLES ----------------
volatile int pulseCount = 0;
float flowRate = 0;
float totalLitres = 0;

// ---------------- BLE ----------------
BLECharacteristic *pCharacteristic;

// ---------------- FLOW INTERRUPT ----------------
void IRAM_ATTR pulseCounter() {
  pulseCount++;
}

// ---------------- FREQUENCY ----------------
float measureFrequency() {
  unsigned long tH = pulseIn(FREQ_PIN, HIGH);
  unsigned long tL = pulseIn(FREQ_PIN, LOW);

  if (tH == 0 || tL == 0) return 0;

  return 1000000.0 / (tH + tL);
}

float getStableFreq() {
  float sum = 0;
  for(int i=0;i<20;i++) {
    sum += measureFrequency();
    delay(10);
  }
  return sum / 20;
}

// ---------------- FLOW CALCULATION ----------------
void calculateFlow() {
  static unsigned long lastTime = 0;

  if (millis() - lastTime >= 1000) {

    detachInterrupt(digitalPinToInterrupt(FLOW_PIN));

    flowRate = (pulseCount / 7.5);   // L/min
    float flowLitres = flowRate / 60.0;

    totalLitres += flowLitres;

    pulseCount = 0;

    attachInterrupt(digitalPinToInterrupt(FLOW_PIN), pulseCounter, RISING);

    lastTime = millis();
  }
}

// ---------------- CLASSIFICATION ----------------
String classifyFuel(float f) {

  if (f >= F_petrol_min && f <= F_petrol_max) {
    return "PURE PETROL";
  }


  float deviation = f - F_petrol_max;

  if (deviation < 15000) {
    return "SLIGHTLY ADULTERATED";
  }
  else if (deviation < 25000) {
    return "MODERATELY ADULTERATED";
  }
  else {
    return "HIGHLY ADULTERATED";
  }
}

// ---------------- BLE SETUP ----------------
void setupBLE() {
  BLEDevice::init("Q-FLO");

  BLEServer *server = BLEDevice::createServer();
  BLEService *service = server->createService("1234");

  pCharacteristic = service->createCharacteristic(
    "5678",
    BLECharacteristic::PROPERTY_NOTIFY | BLECharacteristic::PROPERTY_READ
  );

  pCharacteristic->addDescriptor(new BLE2902());

  service->start();
  BLEDevice::getAdvertising()->start();
}

// ---------------- SETUP ----------------
void setup() {
  Serial.begin(115200);

  pinMode(FREQ_PIN, INPUT);
  pinMode(FLOW_PIN, INPUT);

  attachInterrupt(digitalPinToInterrupt(FLOW_PIN), pulseCounter, RISING);

  setupBLE();
}

// ---------------- LOOP ----------------
void loop() {

  // 🔷 Frequency
  float F_now = getStableFreq();
  String fuelStatus = classifyFuel(F_now);

  // 🔷 Flow
  calculateFlow();

  // ---------------- SERIAL OUTPUT ----------------
  Serial.println("------ Q-FLO ANALYSIS ------");

  Serial.print("Frequency: ");
  Serial.print(F_now);
  Serial.println(" Hz");

  Serial.print("Fuel Quality: ");
  Serial.println(fuelStatus);

  Serial.print("Flow Rate: ");
  Serial.print(flowRate);
  Serial.println(" L/min");

  Serial.print("Total Fuel: ");
  Serial.print(totalLitres);
  Serial.println(" L");

  // ---------------- BLE DATA ----------------
  String data = "{";
  data += "\"freq\":" + String(F_now) + ",";
  data += "\"quality\":\"" + fuelStatus + "\",";
  data += "\"flow\":" + String(flowRate) + ",";
  data += "\"total\":" + String(totalLitres);
  data += "}";

  pCharacteristic->setValue(data.c_str());
  pCharacteristic->notify();

  delay(1000);
}
